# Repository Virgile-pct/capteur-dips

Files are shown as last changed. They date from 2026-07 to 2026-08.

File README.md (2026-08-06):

# Capteur de dips — capteur VBT open source pour le streetlifting

*Open-source velocity-based training (VBT) sensor for weighted dips — ESP32 + IMU.*

Un petit capteur fixé sur la ceinture lestée qui mesure la vitesse de chaque
rep de dips : vitesse moyenne et pic, amplitude, perte de vitesse dans la
série. De quoi piloter l'entraînement avec des données (arrêt de série au
seuil de perte de vitesse, estimation du 1RM sans tirer de max, jauge de
fraîcheur) au lieu du feeling.

Pourquoi ce projet : tous les capteurs VBT du marché sont pensés pour une
barre — appareil pincé sur la barre ou caméra qui suit le disque — et il
n'existe aucun capteur VBT open source maintenu, encore moins pour la
calisthénie lestée, où le corps bouge sous une charge qui pendule. Ce dépôt
comble ce trou, en commençant par les dips.

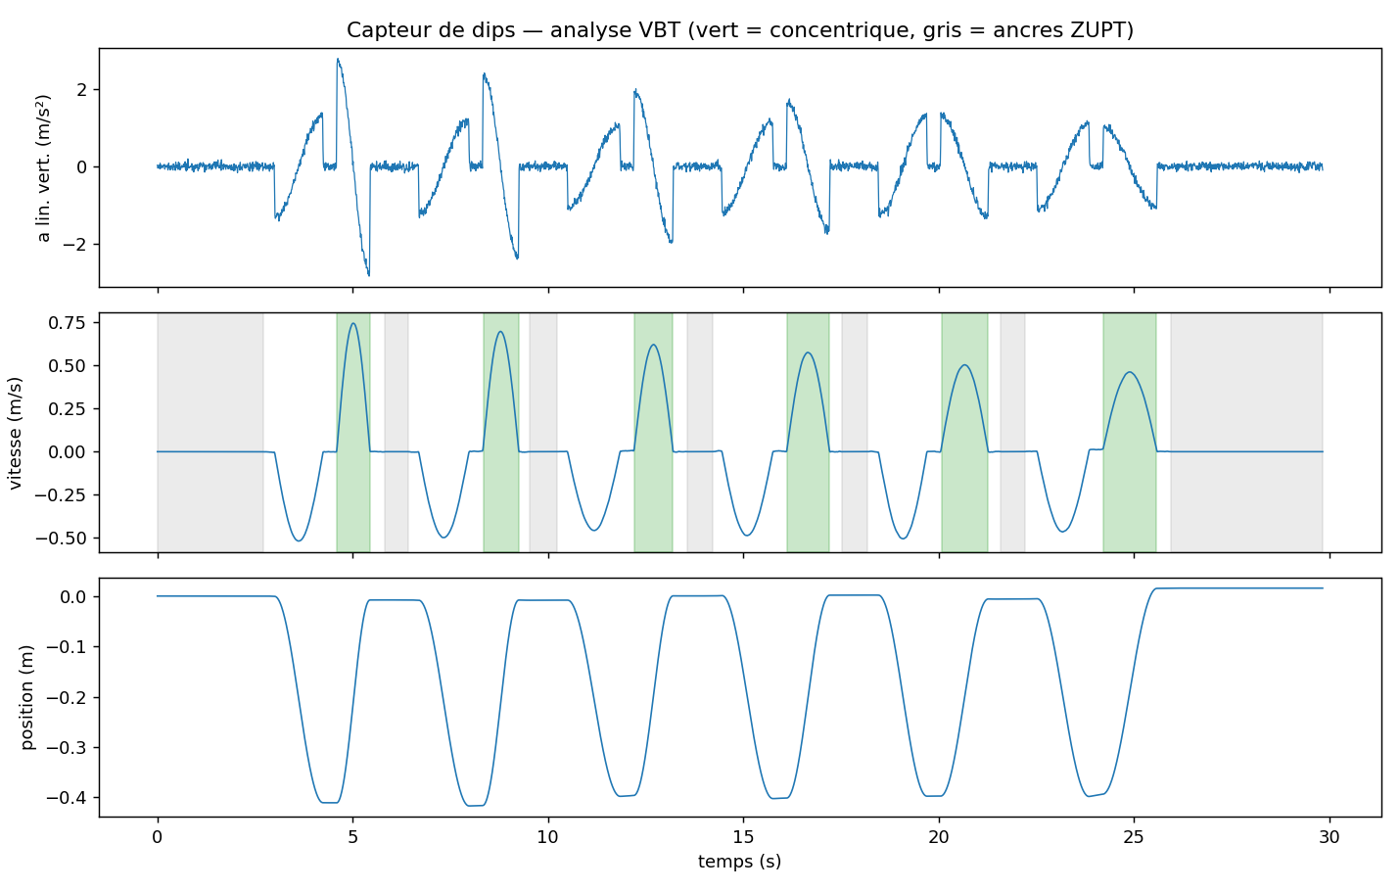
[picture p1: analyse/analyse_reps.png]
Analyse d'une série simulée


**État actuel (V1)** : chaîne d'analyse complète validée sur données
synthétiques — erreur moyenne de 2,3 % sur la vitesse moyenne, 0,8 % sur la
vitesse pic, 0,9 % sur l'amplitude, sur une série de 6 dips simulée avec
bruit, biais et oscillation de ceinture réalistes. Prochaine étape : la
validation sur le vrai matériel (~40 € : ESP32 + MPU6050).

## Architecture V1

L'ESP32 enregistre les mesures brutes de l'IMU à 100 Hz, tout le calcul de
vitesse se fait en Python sur PC. Quand l'algo sera figé et validé sur données
réelles, il sera porté en C++ sur la carte, avec retour temps réel (BLE,
vibreur).

## Contenu

- `firmware/capteur_dips_v1/` — croquis Arduino pour l'ESP32 : lit le MPU6050 à
  100 Hz, calibre le gyro au démarrage (2 s immobile, LED allumée), streame en
  CSV sur le port série. Registres écrits à la main, sans bibliothèque MPU (on
  voit passer la datasheet, c'est le but).
- `firmware/capteur_dips_v2_ble/` — V1 + streaming **BLE** (paquets binaires de
  5 échantillons, ~20 notifications/s) pour couper le câble USB : capteur sur
  batterie, capture sans fil via `analyse/capture_ble.py` (pip install bleak).
  La sortie série reste active en parallèle. L'algo embarqué + le retour
  vibreur viendront en V3.
- `analyse/generateur_reps.py` — fabrique une fausse séance de 6 dips avec
  fatigue, vue par un MPU6050 virtuel (inclinaison, oscillation de ceinture,
  bruit, biais). Permet de développer SANS le matériel.
- `analyse/analyse_reps.py` — l'algo : détection d'immobilité, calibration,
  suivi de gravité (filtre complémentaire), intégration avec ZUPT et correction
  de dérive, découpage en reps, métriques VBT (v moyenne, v pic, ROM, perte de
  vitesse). Sort un tableau + un graphique de contrôle.
- `analyse/capture_serie.py` — enregistre le flux série du vrai capteur dans un
  CSV (nécessite `pip install pyserial`).
- `boitier/generer_boitier.py` — génère le boîtier imprimable en 3D
  (`boitier_capteur_v1.stl`) : carte + GY-521 montés rigides, ailes à fente
  pour la sangle de la ceinture, échancrure USB, couvercle à friction. Toutes
  les cotes sont paramétrables en tête de script — à la livraison, mesurer la
  carte au pied à coulisse, ajuster `L_CARTE`/`l_CARTE`, relancer.

## Boucle de dev sans matériel (dispo tout de suite)

```
cd analyse
python generateur_reps.py
python analyse_reps.py reps_simulees.csv --verite verite_terrain.json
```

Le second script imprime les reps détectées et l'erreur par rapport à la vérité
terrain simulée — c'est le banc de test de l'algo.

## Quand le matériel arrive

1. Câbler le GY-521 : VCC→3V3, GND→GND, SDA→GPIO21, SCL→GPIO22.
2. IDE Arduino : ajouter l'URL des cartes ESP32 dans Préférences
   (`https://espressif.github.io/arduino-esp32/package_esp32_index.json`),
   installer « esp32 » dans le gestionnaire de cartes, choisir
   « ESP32 Dev Module », port série à 115200.
3. Flasher `firmware/capteur_dips_v1`, laisser le capteur immobile pendant la
   calibration (LED allumée ~2 s).
4. Capturer une séance : `python capture_serie.py --sortie seance.csv`
   (rester immobile 2-3 s au début, marquer une vraie pause en haut entre les
   reps — ce sont les ancres qui annulent la dérive).
5. Analyser : `python analyse_reps.py seance.csv`.

## Impression du boîtier

PLA ou PETG (rigide = mesure propre ; garder le TPU pour plus tard si le
confort le demande), 0,2 mm, 3 périmètres, 20 % de remplissage, **sans
support** — tout est dessiné pour. Le STL contient le corps et le couvercle
côte à côte ; si le slicer signale des coques qui se chevauchent, c'est
normal (géométrie additive), il les fusionne tout seul. Monter le GY-521 à
plat entre ses cales (barrette soudée vers le HAUT), 4 fils Dupont F-F vers
la carte par le passage central, un point de colle chaude ou de la mousse
sous la carte pour caler. Si le couvercle force sur les broches de la carte,
réduire `h_j` (hauteur de jupe) dans le script. L'orientation du capteur dans
le boîtier n'a aucune importance : l'algo retrouve la direction de la gravité
tout seul.

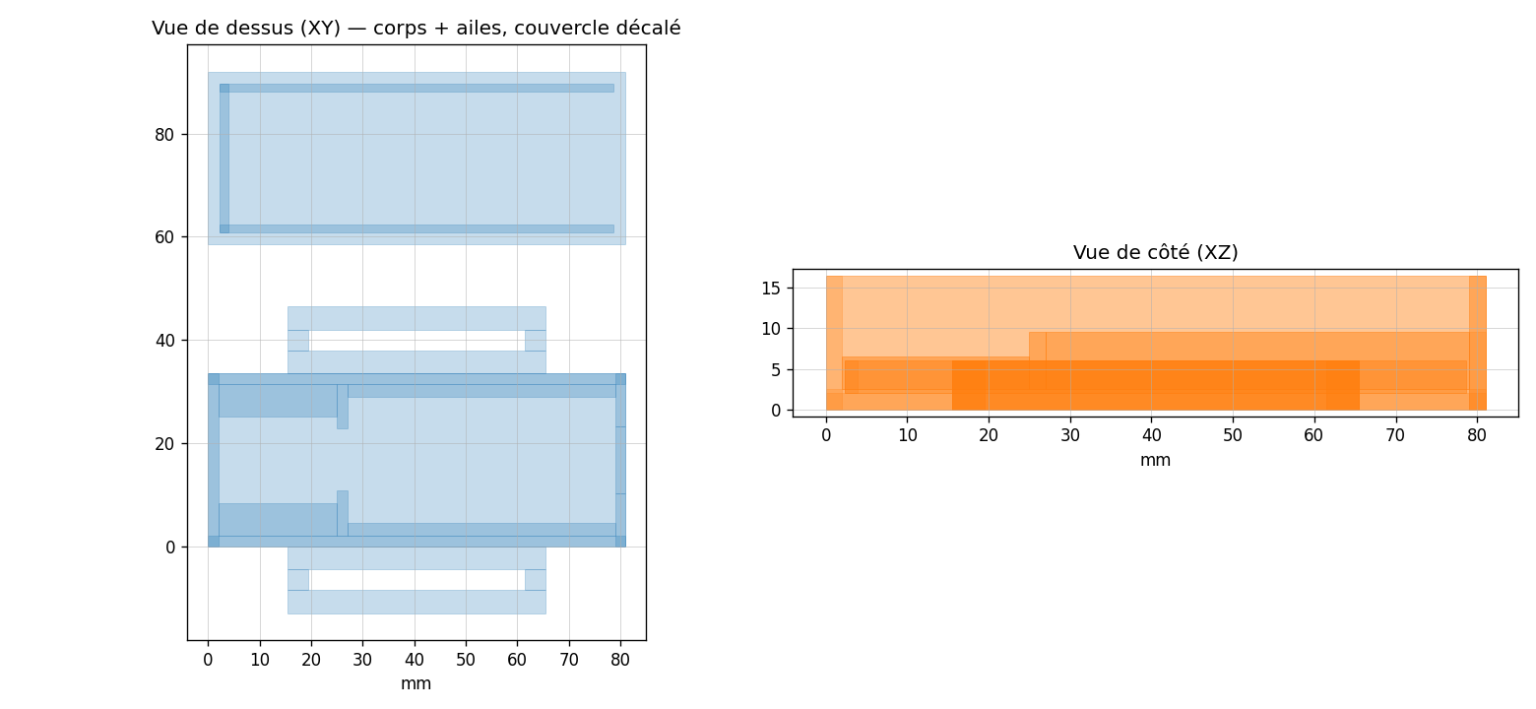
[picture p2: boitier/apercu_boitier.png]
Boîtier 3D — vues de dessus et de côté


## Feuille de route

- [x] Algo complet testé sur données synthétiques
- [x] Boîtier V1 imprimable généré (PLA/PETG, sans support)
- [ ] Flasher sur ESP32 réel et capturer de vraies séries
- [ ] Valider sur vraies reps (vidéo 240 fps comme vérité terrain)
- [ ] Re-régler les seuils (`SEUIL_*` en tête d'analyse_reps.py) sur le réel
- [ ] Porter l'algo en C++ sur l'ESP32 + retour BLE/vibreur
- [ ] Version force : cellule de charge dans la chaîne (protocole BLE Tindeq
  Progressor pour la compatibilité avec l'écosystème existant)
- [ ] Mode barre (le même capteur sanglé sur une barre : cas plus simple)

## Licence

[MIT](LICENSE) — utilise, modifie, partage. Si tu construis le tien, raconte.

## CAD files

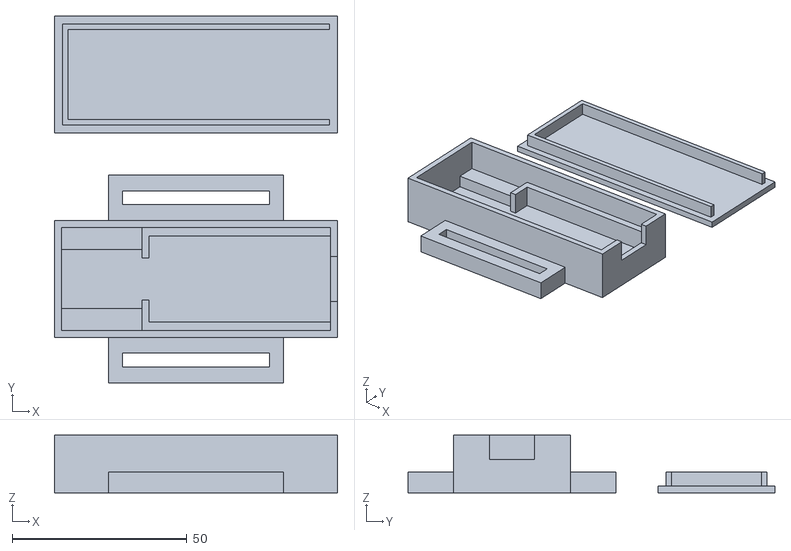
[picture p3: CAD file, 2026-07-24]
boitier/boitier_capteur_v1.stl
81.0 x 105.0 x 16.5

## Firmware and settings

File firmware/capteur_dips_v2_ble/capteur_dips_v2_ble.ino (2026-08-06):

// ============================================================================
// Capteur de dips V2 — enregistreur ESP32 + MPU6050 avec streaming BLE
//
// Étape 1 du chantier « couper le câble » : mêmes mesures brutes que la V1
// (100 Hz), mais diffusées AUSSI en Bluetooth Low Energy vers un PC ou un
// téléphone. La chaîne d'analyse Python reste inchangée : capture_ble.py
// reconstitue exactement le même CSV que la liaison série. L'algo embarqué
// et le vibreur viendront en V3, une fois le sans-fil validé.
//
// Double sortie simultanée :
//   - USB série 115200 : CSV identique à la V1 (le mode filaire marche toujours)
//   - BLE : paquets binaires de 5 échantillons (voir FORMAT ci-dessous)
//
// FORMAT d'un échantillon BLE (16 octets, little-endian) :
//   uint32  t_ms                  horodatage carte
//   int16   ax, ay, az            accélération × 500  (±65 m/s² de plage)
//   int16   gx, gy, gz            gyroscope × 10      (°/s, biais retiré)
// Un paquet notify = 5 échantillons = 80 octets, ~20 notifications/s.
//
// LED : fixe pendant la calibration (2 s, NE PAS BOUGER), clignotement lent
// en attente de connexion BLE, allumée fixe quand un client est connecté,
// clignotement rapide = MPU6050 introuvable.
// ============================================================================

#include <Wire.h>
#include <BLEDevice.h>
#include <BLEServer.h>
#include <BLEUtils.h>
#include <BLE2902.h>

// ---- Réglages ---------------------------------------------------------------
#define BROCHE_SDA        21
#define BROCHE_SCL        22
#define BROCHE_LED        2
#define FREQ_ECH_HZ       100
#define N_CALIBRATION     200
#define ECH_PAR_PAQUET    5

#define NOM_BLE           "CapteurDips"
#define UUID_SERVICE      "b5f0a1c0-9d6b-4b7a-8e1f-3c2a7d9e0001"
#define UUID_CARAC_DATA   "b5f0a1c0-9d6b-4b7a-8e1f-3c2a7d9e0002"

// ---- Registres MPU6050 ------------------------------------------------------
#define MPU_ADRESSE       0x68
#define REG_SMPLRT_DIV    0x19
#define REG_CONFIG        0x1A
#define REG_GYRO_CONFIG   0x1B
#define REG_ACCEL_CONFIG  0x1C
#define REG_ACCEL_XOUT_H  0x3B
#define REG_PWR_MGMT_1    0x6B
#define REG_WHO_AM_I      0x75

const float ACCEL_M_S2_PAR_LSB = 9.80665f / 4096.0f;   // ±8 g
const float GYRO_DPS_PAR_LSB   = 1.0f / 65.5f;         // ±500 °/s
const uint32_t PERIODE_US = 1000000UL / FREQ_ECH_HZ;

float biaisGyro[3] = {0, 0, 0};
uint32_t prochainEchantillonUs = 0;
uint32_t t0Ms = 0;

BLECharacteristic *caracData = nullptr;
volatile bool clientConnecte = false;
uint8_t paquet[16 * ECH_PAR_PAQUET];
int idxPaquet = 0;

// ---- BLE : gestion de la connexion ------------------------------------------
class Callbacks : public BLEServerCallbacks {
  void onConnect(BLEServer *) override { clientConnecte = true; }
  void onDisconnect(BLEServer *srv) override {
    clientConnecte = false;
    srv->getAdvertising()->start();       // redevenir visible aussitôt
  }
};

// ---- Accès I2C bas niveau (identique V1) ------------------------------------
void ecrireRegistre(uint8_t reg, uint8_t valeur) {
  Wire.beginTransmission(MPU_ADRESSE);
  Wire.write(reg);
  Wire.write(valeur);
  Wire.endTransmission();
}

uint8_t lireRegistre(uint8_t reg) {
  Wire.beginTransmission(MPU_ADRESSE);
  Wire.write(reg);
  Wire.endTransmission(false);
  Wire.requestFrom(MPU_ADRESSE, (uint8_t)1);
  return Wire.read();
}

void lireIMU(float accel[3], float gyro[3]) {
  uint8_t brut[14];
  Wire.beginTransmission(MPU_ADRESSE);
  Wire.write(REG_ACCEL_XOUT_H);
  Wire.endTransmission(false);
  Wire.requestFrom(MPU_ADRESSE, (uint8_t)14);
  for (int i = 0; i < 14; i++) brut[i] = Wire.read();
  for (int i = 0; i < 3; i++) {
    int16_t a = (int16_t)((brut[2 * i] << 8) | brut[2 * i + 1]);
    int16_t g = (int16_t)((brut[8 + 2 * i] << 8) | brut[9 + 2 * i]);
    accel[i] = a * ACCEL_M_S2_PAR_LSB;
    gyro[i]  = g * GYRO_DPS_PAR_LSB;
  }
}

// ---- Encodage d'un échantillon dans le paquet BLE ---------------------------
void empiler(uint32_t tMs, const float accel[3], const float gyro[3]) {
  uint8_t *p = paquet + 16 * idxPaquet;
  memcpy(p, &tMs, 4);
  for (int i = 0; i < 3; i++) {
    int16_t v = (int16_t)lroundf(accel[i] * 500.0f);
    memcpy(p + 4 + 2 * i, &v, 2);
  }
  for (int i = 0; i < 3; i++) {
    int16_t v = (int16_t)lroundf(gyro[i] * 10.0f);
    memcpy(p + 10 + 2 * i, &v, 2);
  }
  if (++idxPaquet >= ECH_PAR_PAQUET) {
    idxPaquet = 0;
    if (clientConnecte && caracData) {
      caracData->setValue(paquet, sizeof(paquet));
      caracData->notify();
    }
  }
}

// ---- Initialisation ---------------------------------------------------------
void setup() {
  Serial.begin(115200);
  pinMode(BROCHE_LED, OUTPUT);
  Wire.begin(BROCHE_SDA, BROCHE_SCL, 400000);

  delay(100);
  if (lireRegistre(REG_WHO_AM_I) != 0x68) {
    Serial.println("# ERREUR : MPU6050 introuvable. Verifier cablage SDA=21 SCL=22.");
    while (true) {
      digitalWrite(BROCHE_LED, !digitalRead(BROCHE_LED));
      delay(100);
    }
  }

  ecrireRegistre(REG_PWR_MGMT_1, 0x80);
  delay(100);
  ecrireRegistre(REG_PWR_MGMT_1, 0x01);
  ecrireRegistre(REG_CONFIG, 0x03);
  ecrireRegistre(REG_SMPLRT_DIV, 9);
  ecrireRegistre(REG_GYRO_CONFIG, 0x08);
  ecrireRegistre(REG_ACCEL_CONFIG, 0x10);
  delay(100);

  // Calibration gyro : immobile, LED fixe
  Serial.println("# Calibration gyro : immobile 2 s...");
  digitalWrite(BROCHE_LED, HIGH);
  float accel[3], gyro[3], somme[3] = {0, 0, 0};
  for (int n = 0; n < N_CALIBRATION; n++) {
    lireIMU(accel, gyro);
    for (int i = 0; i < 3; i++) somme[i] += gyro[i];
    delay(1000 / FREQ_ECH_HZ);
  }
  for (int i = 0; i < 3; i++) biaisGyro[i] = somme[i] / N_CALIBRATION;
  digitalWrite(BROCHE_LED, LOW);

  // BLE : serveur + service + caractéristique notify
  BLEDevice::init(NOM_BLE);
  BLEDevice::setMTU(185);
  BLEServer *serveur = BLEDevice::createServer();
  serveur->setCallbacks(new Callbacks());
  BLEService *service = serveur->createService(UUID_SERVICE);
  caracData = service->createCharacteristic(UUID_CARAC_DATA,
                                            BLECharacteristic::PROPERTY_NOTIFY);
  caracData->addDescriptor(new BLE2902());
  service->start();
  BLEAdvertising *pub = BLEDevice::getAdvertising();
  pub->addServiceUUID(UUID_SERVICE);
  pub->start();

  Serial.println("# BLE pret : advertising sous le nom CapteurDips");
  Serial.println("t_ms,ax,ay,az,gx,gy,gz");
  t0Ms = millis();
  prochainEchantillonUs = micros();
}

// ---- Boucle 100 Hz : série + BLE, LED d'état --------------------------------
void loop() {
  while ((int32_t)(micros() - prochainEchantillonUs) < 0) {}
  prochainEchantillonUs += PERIODE_US;

  float accel[3], gyro[3];
  lireIMU(accel, gyro);
  for (int i = 0; i < 3; i++) gyro[i] -= biaisGyro[i];

  uint32_t tMs = millis() - t0Ms;
  Serial.printf("%lu,%.4f,%.4f,%.4f,%.3f,%.3f,%.3f\n", (unsigned long)tMs,
                accel[0], accel[1], accel[2], gyro[0], gyro[1], gyro[2]);
  empiler(tMs, accel, gyro);

  // LED : fixe si connecté, battement lent sinon (visible sans être un phare)
  digitalWrite(BROCHE_LED, clientConnecte ? HIGH : ((tMs % 2000) < 100));
}

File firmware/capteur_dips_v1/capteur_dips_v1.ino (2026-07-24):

// ============================================================================
// Capteur de dips V1 — enregistreur brut ESP32 + MPU6050 (GY-521)
//
// Rôle volontairement minimal (palier 1 de la doc projet) : lire l'IMU à
// 100 Hz, calibrer le biais gyro au démarrage, et streamer les mesures en CSV
// sur le port série. Tout le calcul de vitesse se fait côté PC en Python
// (analyse/analyse_reps.py) — on portera l'algo en C++ ici quand il sera figé.
//
// Câblage GY-521 -> ESP32 DevKit :
//   VCC -> 3V3, GND -> GND, SDA -> GPIO21, SCL -> GPIO22 (AD0 laissé en l'air)
//
// Sortie série (115200 bauds) : t_ms,ax,ay,az,gx,gy,gz
//   accéléro en m/s², gyro en °/s, lignes de contexte préfixées par '#'
//
// Protocole de mesure : poser/tenir le capteur IMMOBILE pendant les 2 s de
// calibration (LED bleue allumée), puis faire la série. L'immobilité entre les
// reps (verrouillage en haut) sert d'ancre ZUPT à l'algo Python.
// ============================================================================

#include <Wire.h>

// ---- Réglages ---------------------------------------------------------------
#define BROCHE_SDA        21
#define BROCHE_SCL        22
#define BROCHE_LED        2        // LED bleue intégrée du DevKit
#define FREQ_ECH_HZ       100      // fréquence d'échantillonnage
#define N_CALIBRATION     200      // 2 s de calibration à 100 Hz
// #define SORTIE_PLOTTER          // décommenter pour le Serial Plotter Arduino

// ---- Registres MPU6050 (datasheet "MPU-6000/6050 Register Map") -------------
#define MPU_ADRESSE       0x68     // AD0 à la masse
#define REG_SMPLRT_DIV    0x19
#define REG_CONFIG        0x1A
#define REG_GYRO_CONFIG   0x1B
#define REG_ACCEL_CONFIG  0x1C
#define REG_ACCEL_XOUT_H  0x3B
#define REG_PWR_MGMT_1    0x6B
#define REG_WHO_AM_I      0x75

// Échelles : ±8 g -> 4096 LSB/g ; ±500 °/s -> 65.5 LSB/(°/s)
const float ACCEL_M_S2_PAR_LSB = 9.80665f / 4096.0f;
const float GYRO_DPS_PAR_LSB   = 1.0f / 65.5f;

const uint32_t PERIODE_US = 1000000UL / FREQ_ECH_HZ;

float biaisGyro[3] = {0, 0, 0};
uint32_t prochainEchantillonUs = 0;
uint32_t t0Ms = 0;

// ---- Accès I2C bas niveau ---------------------------------------------------
void ecrireRegistre(uint8_t reg, uint8_t valeur) {
  Wire.beginTransmission(MPU_ADRESSE);
  Wire.write(reg);
  Wire.write(valeur);
  Wire.endTransmission();
}

uint8_t lireRegistre(uint8_t reg) {
  Wire.beginTransmission(MPU_ADRESSE);
  Wire.write(reg);
  Wire.endTransmission(false);          // restart, pas de stop
  Wire.requestFrom(MPU_ADRESSE, (uint8_t)1);
  return Wire.read();
}

// Lecture en rafale des 14 octets accel+temp+gyro (big-endian, int16 signés)
void lireIMU(float accel[3], float gyro[3]) {
  uint8_t brut[14];
  Wire.beginTransmission(MPU_ADRESSE);
  Wire.write(REG_ACCEL_XOUT_H);
  Wire.endTransmission(false);
  Wire.requestFrom(MPU_ADRESSE, (uint8_t)14);
  for (int i = 0; i < 14; i++) brut[i] = Wire.read();

  for (int i = 0; i < 3; i++) {
    int16_t a = (int16_t)((brut[2 * i] << 8) | brut[2 * i + 1]);
    int16_t g = (int16_t)((brut[8 + 2 * i] << 8) | brut[9 + 2 * i]);
    accel[i] = a * ACCEL_M_S2_PAR_LSB;
    gyro[i]  = g * GYRO_DPS_PAR_LSB;
  }
}

// ---- Initialisation ---------------------------------------------------------
void setup() {
  Serial.begin(115200);
  pinMode(BROCHE_LED, OUTPUT);
  Wire.begin(BROCHE_SDA, BROCHE_SCL, 400000);   // I2C rapide 400 kHz

  delay(100);
  uint8_t whoami = lireRegistre(REG_WHO_AM_I);
  if (whoami != 0x68) {
    Serial.printf("# ERREUR : MPU6050 introuvable (WHO_AM_I=0x%02X). Verifier cablage SDA=21 SCL=22.\n", whoami);
    while (true) {                        // clignote vite = panne
      digitalWrite(BROCHE_LED, !digitalRead(BROCHE_LED));
      delay(100);
    }
  }

  ecrireRegistre(REG_PWR_MGMT_1, 0x80);   // reset
  delay(100);
  ecrireRegistre(REG_PWR_MGMT_1, 0x01);   // réveil, horloge PLL gyro X (plus stable que l'oscillo interne)
  ecrireRegistre(REG_CONFIG, 0x03);       // filtre passe-bas interne : 44 Hz accel / 42 Hz gyro
  ecrireRegistre(REG_SMPLRT_DIV, 9);      // 1 kHz / (1+9) = 100 Hz
  ecrireRegistre(REG_GYRO_CONFIG, 0x08);  // ±500 °/s
  ecrireRegistre(REG_ACCEL_CONFIG, 0x10); // ±8 g (marge large, un dip reste < 2 g)
  delay(100);

  // Calibration du biais gyro : NE PAS BOUGER pendant que la LED est allumée
  Serial.println("# Calibration gyro : immobile 2 s...");
  digitalWrite(BROCHE_LED, HIGH);
  float accel[3], gyro[3], sommeG[3] = {0, 0, 0}, sommeNormeA = 0;
  for (int n = 0; n < N_CALIBRATION; n++) {
    lireIMU(accel, gyro);
    for (int i = 0; i < 3; i++) sommeG[i] += gyro[i];
    sommeNormeA += sqrtf(accel[0]*accel[0] + accel[1]*accel[1] + accel[2]*accel[2]);
    delay(1000 / FREQ_ECH_HZ);
  }
  for (int i = 0; i < 3; i++) biaisGyro[i] = sommeG[i] / N_CALIBRATION;
  digitalWrite(BROCHE_LED, LOW);

  Serial.printf("# biais gyro (deg/s) : %.3f %.3f %.3f | norme accel au repos : %.3f m/s2\n",
                biaisGyro[0], biaisGyro[1], biaisGyro[2], sommeNormeA / N_CALIBRATION);
  Serial.println("t_ms,ax,ay,az,gx,gy,gz");

  t0Ms = millis();
  prochainEchantillonUs = micros();
}

// ---- Boucle : échantillonnage cadencé à 100 Hz ------------------------------
void loop() {
  // attente active jusqu'au prochain tick (précis, sans dérive cumulative)
  while ((int32_t)(micros() - prochainEchantillonUs) < 0) {}
  prochainEchantillonUs += PERIODE_US;

  float accel[3], gyro[3];
  lireIMU(accel, gyro);
  for (int i = 0; i < 3; i++) gyro[i] -= biaisGyro[i];

#ifdef SORTIE_PLOTTER
  // Vue temps réel dans le Serial Plotter : norme accel - g, et norme gyro
  float normeA = sqrtf(accel[0]*accel[0] + accel[1]*accel[1] + accel[2]*accel[2]);
  float normeG = sqrtf(gyro[0]*gyro[0] + gyro[1]*gyro[1] + gyro[2]*gyro[2]);
  Serial.printf("accel_lin:%.3f,gyro:%.2f\n", normeA - 9.81f, normeG);
#else
  Serial.printf("%lu,%.4f,%.4f,%.4f,%.3f,%.3f,%.3f\n",
                (unsigned long)(millis() - t0Ms),
                accel[0], accel[1], accel[2], gyro[0], gyro[1], gyro[2]);
#endif
}

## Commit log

2026-07-24 Capteur de dips V1 : firmware ESP32, algo VBT valide en simulation, boitier 3D
    - Firmware enregistreur brut ESP32 + MPU6050 (100 Hz, CSV serie, registres a la main)
    - Chaine d'analyse Python : ZUPT, suivi de gravite, decoupage en reps, metriques VBT
    - Banc de test synthetique : 6 dips simules, erreur 2,3 % sur la vitesse moyenne
    - Boitier imprimable 3D parametrique (STL genere, sans support)
    [boitier_capteur_v1.stl]
2026-08-05 Lecons de la premiere session sur capteur reel
    - Detection d'immobilite par VARIABILITE (accel + gyro) : un seuil absolu
    gyro casse des que le biais derive avec la temperature
    - Calibration de l'analyse sur la plage la plus calme du fichier, plus
    forcement la premiere (tolere un depart agite)
    - Nouveau calibre_6faces.py : offsets/gains accelero par axe, mesures sur
    l'exemplaire reel (Z : +1.23 m/s2 d'offset d'usine !) ; applique
    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
2026-08-05 ZUPT a ancres ponctuelles + garde-fous, valide sur 3 jeux de donnees
    La serie explosive reelle (verrouillages ~0,2 s) a impose une refonte des ancres :
    - ancres PONCTUELLES (zero de vitesse epingle au coeur de la pause) au lieu de
    plages entieres : le lissage de la detection ne mord plus le debut des phases
    - deux niveaux : pause longue = ancre d office ; pause courte = ancre seulement
    si entouree de mouvement franc (contexte), sinon les phases lentes d une rep
    fatiguee passent pour des pauses et la hachent
    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
2026-08-05 Outil de profil charge-vitesse (regression + estimation 1RM par gamme de MVT)
    Premier profil reel mesure : 4 paliers (PdC a +40 kg), R2 = 0,995 sur la droite.
2026-08-05 Ajout du script de profil charge-vitesse (oublie du commit precedent, gitignore trop large)
2026-08-06 Firmware V2 : streaming BLE + capture sans fil (chantier batterie, etape 1)
    - capteur_dips_v2_ble.ino : V1 + serveur BLE (service custom, notify 20 Hz,
    5 echantillons/paquet en binaire 16 octets), double sortie serie+BLE,
    LED d etat connexion. Compile : 85 pct de la flash (pile Bluedroid).
    - capture_ble.py (bleak) : scan, connexion, decodage -> CSV identique au
    filaire, la chaine d analyse fonctionne sans modification.
    - Non teste en radio (materiel batterie en cours de livraison) ; valide a
    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
2026-08-07 Tableau de bord web : donnees reelles, profil charge-vitesse, live BLE
    - docs/index.html : page unique autonome (canvas maison, palette validee,
    sombre) — references athlete, profil charge-vitesse interactif, les 5
    seances rep par rep colorees par zone de perte, fiche technique avec
    calibration 6 faces, feuille de route, jalons
    - Section live : connexion Web Bluetooth au firmware V2 (flux 100 Hz en
    direct + enregistrement CSV depuis le navigateur, Chrome requis)
    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
2026-08-07 Dashboard : cloisonnement des modules + hauteurs canvas garanties
    Lecon du premier deploiement (ecran blanc geant chez Virgile) : un donnees.js
    pas encore propage faisait planter le script entier, et des canvas sans
    hauteur CSS s etiraient au ratio intrinseque. Correctifs :
    - chaque module dans son try/catch : une panne locale ne tue plus la page
    - hauteur CSS explicite sur tous les canvas (plus de geant blanc possible)
    - rechargement auto unique si donnees.js manque (fenetre de deploiement)
2026-08-07 Canvas en rendu logiciel (willReadFrequently) : contourne les pilotes GPU defaillants
    Symptome observe sur le Chrome de Virgile : canvas blanc + icone cassee sans
    aucune erreur JS = echec d allocation du buffer GPU du canvas. Le contexte 2D
    est desormais cree avec willReadFrequently:true, qui force la rasterisation
    CPU — meme rendu partout, quel que soit l etat du pilote graphique.
2026-08-07 Graphiques reecrits en SVG : fin des canvas blancs
    Le canvas a echoue deux fois chez Virgile (rectangle blanc + icone d image
    cassee, sans aucune erreur JS) et par intermittence ailleurs : allocation du
    buffer graphique refusee. Les trois graphiques sont desormais du DOM SVG.
    - aucune allocation GPU, aucune dependance au pilote ni a la taille max
    - le viewBox gere l echelle : plus de ResizeObserver ni de dessin differe,
    donc plus de fenetre ou le graphique peut rester vide
    - chaque point et chaque barre est un element : le survol devient un
    evenement natif au lieu d un calcul de collision
    - le flux temps reel utilise des polylignes mises a jour en place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
2026-08-08 Etude d implantation 3D de la carte V3 (SVG interactif)
    Vue 3D orbitable du PCB custom envisage : module ESP32-S3-MINI-1 pre-certifie,
    IMU, charge USB-C via TP4056, regulateur LDO, driver de vibreur, accu sous la
    carte. Rendu en SVG pur (projection + tri du peintre par couches physiques),
    pas de canvas. Vue eclatee, isolement des pieces au survol de la legende.
    Contient aussi la nomenclature chiffree a 100 unites (carte assemblee 6,26 EUR,
    cout de revient complet ~20 EUR) et les six choix de conception justifies.
2026-08-08 Vue 3D : boitier, couvercle, passages de sangle et sangle — produit fini
    - Coque 45 x 31 x 14 mm parois 1,2, mur droit perce pour l USB-C, deux ailes
    a fente 40 x 4 pour la sangle de ceinture, couvercle + marquage
    - Vibreur repositionne a l interieur, colle sous le couvercle (il suit le
    couvercle dans la vue eclatee)
    - Trois modes : produit fini (coque opaque, contenu non calcule), voir
    l interieur (coque a 17 %), sans boitier ; l eclate bascule seul en mode
    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
